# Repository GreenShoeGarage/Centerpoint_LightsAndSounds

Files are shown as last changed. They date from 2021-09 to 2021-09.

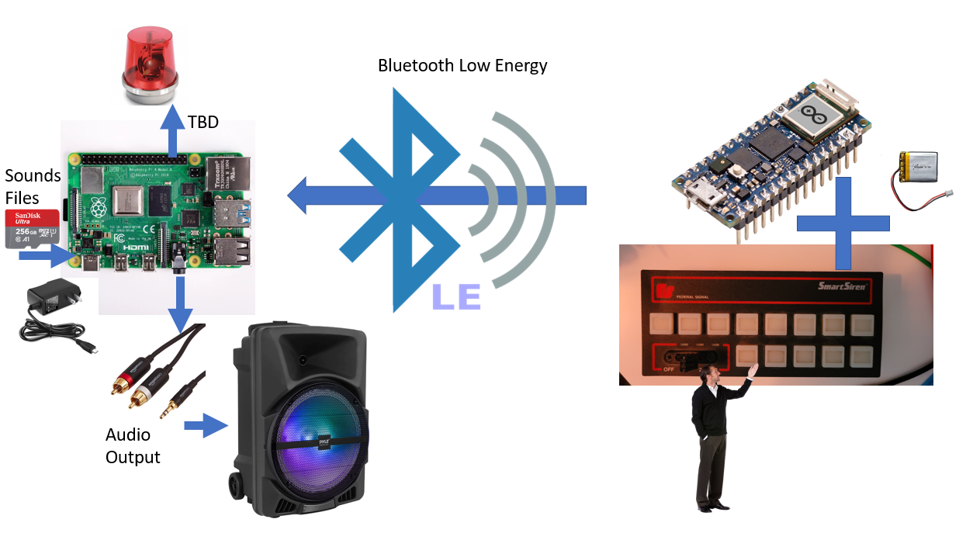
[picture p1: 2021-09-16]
Documentation/Photos/SystemArchitecture.png

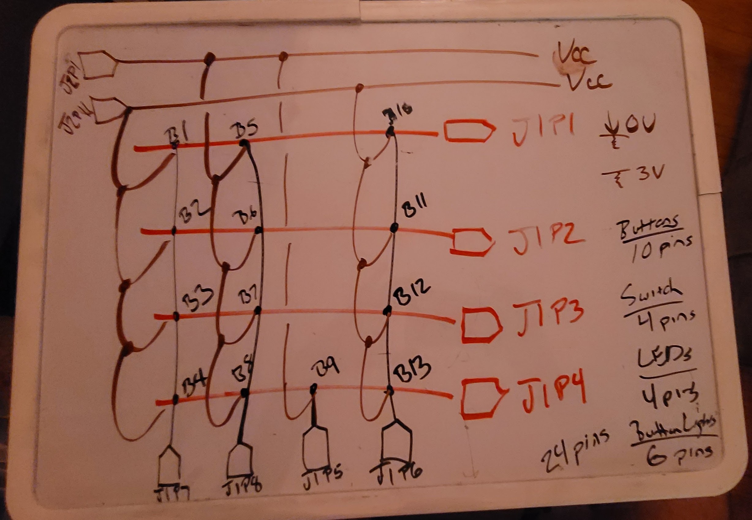
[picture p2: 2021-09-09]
Documentation/Photos/Keypad_MatrixCircuit.jpg

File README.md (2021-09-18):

# Centerpoint Lights and Sounds

| RP2040 Pin | Keypad PCB Header Row (J) | Keypad PCB Header Pin (P) | Pin Function |
|---|---|---|---|
| D2 | J1 | 5 | Keypad Column for Button 9 |
| D3 | J1 | 6 | Keypad Column for Buttons 10, 11, 12, 13 |
| D4 | J1 | 7 | Keypad Column for Buttons 1,2,3,4 |
| D5 | J1 | 8 | Keypad Column for Buttons 5, 6, 7, 8 |
| D6 | J2 | 1 | Keypad Row for Buttons 5, 6, 7, 8, 9 |
| D7 | J2 | 3 |  Button 1 LED GND AND GREEN LED GROUND |
| D8 | J2 | 5 |  Button 2 LED GND AND YELLOW LED GROUND |
| D9 | J2 | 7 |  GND for RED LED AND MAYBE  Button 3 LED GND**** |
| D10 | J2 | 11 | Keypad Row for Buttons 1,2,3,4,10,11,12,13 |
| D11 | SW | BLACK | VCC for Switch |
| D12 | J2 | 4 | Buttons 8 and 13 LED GND |
| D12 | J2 | 6 | Buttons 5 and 10 LED GND |
| D12 | J2 | 8 | Buttons 6 and 11 LED GND |
| D12 | J2 | 9 | Buttons 4 and 9 LED GND |
| D12 | J2 | 10 | Buttons 7 and 12 LED GND |
| D13 | SW | RED | Switch Position 2 |
| VCC | J2 | 2 | Top Row of Rubber Buttons (1-8) LED Vcc |
| VCC | J2 | 13 | Bottom Row of Rubber Buttons (9-13) LED Vcc AND  GYR LEDs Vcc |
| A0 | J1 | 1 | Buttons 1 and 5 and 10 |
| A1 | J1 | 2 | Buttons 2 and 6 and 11 |
| A2 | J1 | 3 |  Buttons 3 and 7 and 12 |
| A3 | J1 | 4 |  Buttons 4 and 8 and 9 and 13 |
| A4 | unassigned | unassigned | Reserved for I2C |
| A5 | unassigned | unassigned | Reserved for I2C |
| A6 | SW | GREEN | Switch Position 1 |
| A7 | SW | WHITE | Switch Position 3 |

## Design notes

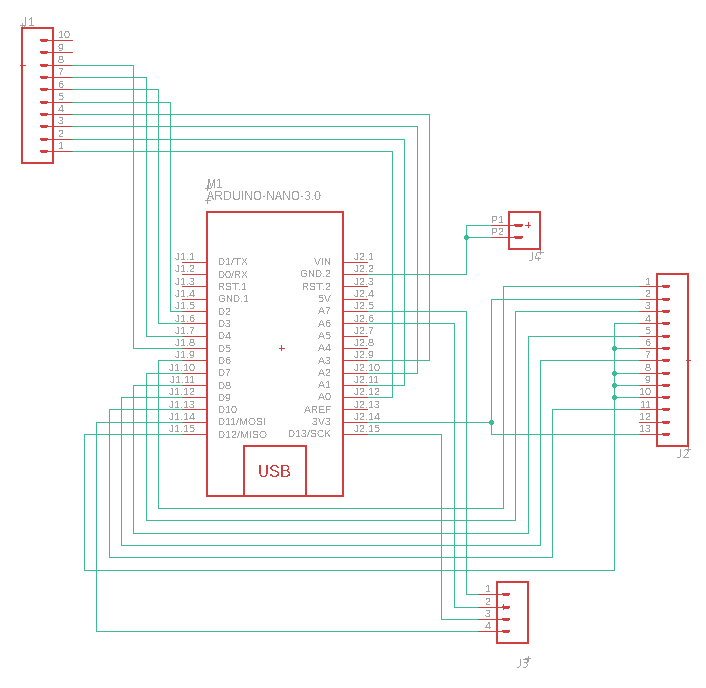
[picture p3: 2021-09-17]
Documentation/Photos/AdapterPCB_Schematic.png

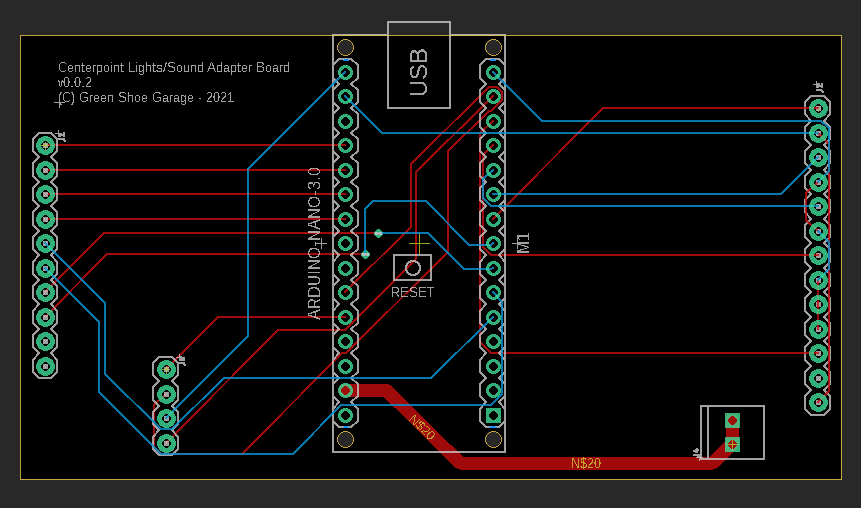
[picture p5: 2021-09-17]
Documentation/Photos/AdapterPCB_BoardLayout.png

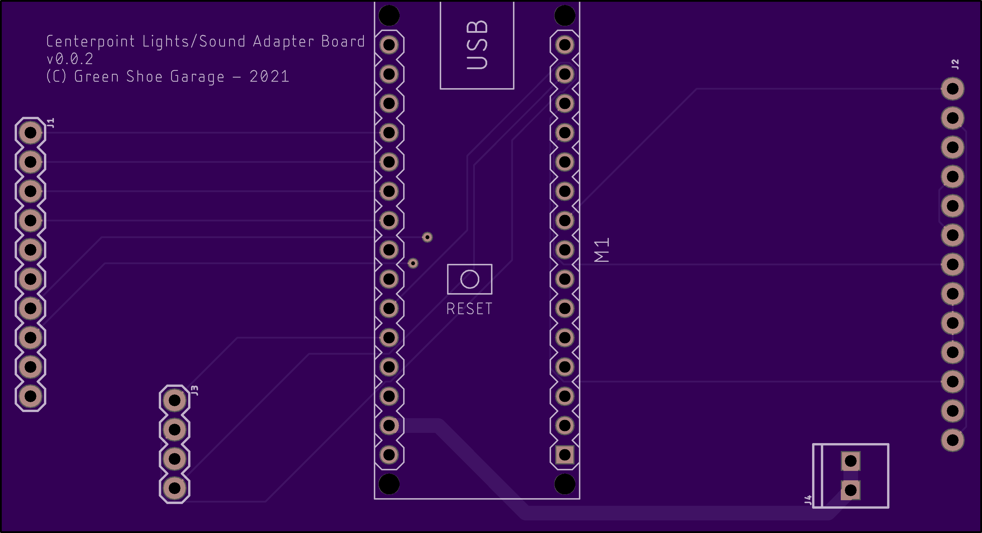
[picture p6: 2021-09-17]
Documentation/Photos/AdapterPCB_Top.png

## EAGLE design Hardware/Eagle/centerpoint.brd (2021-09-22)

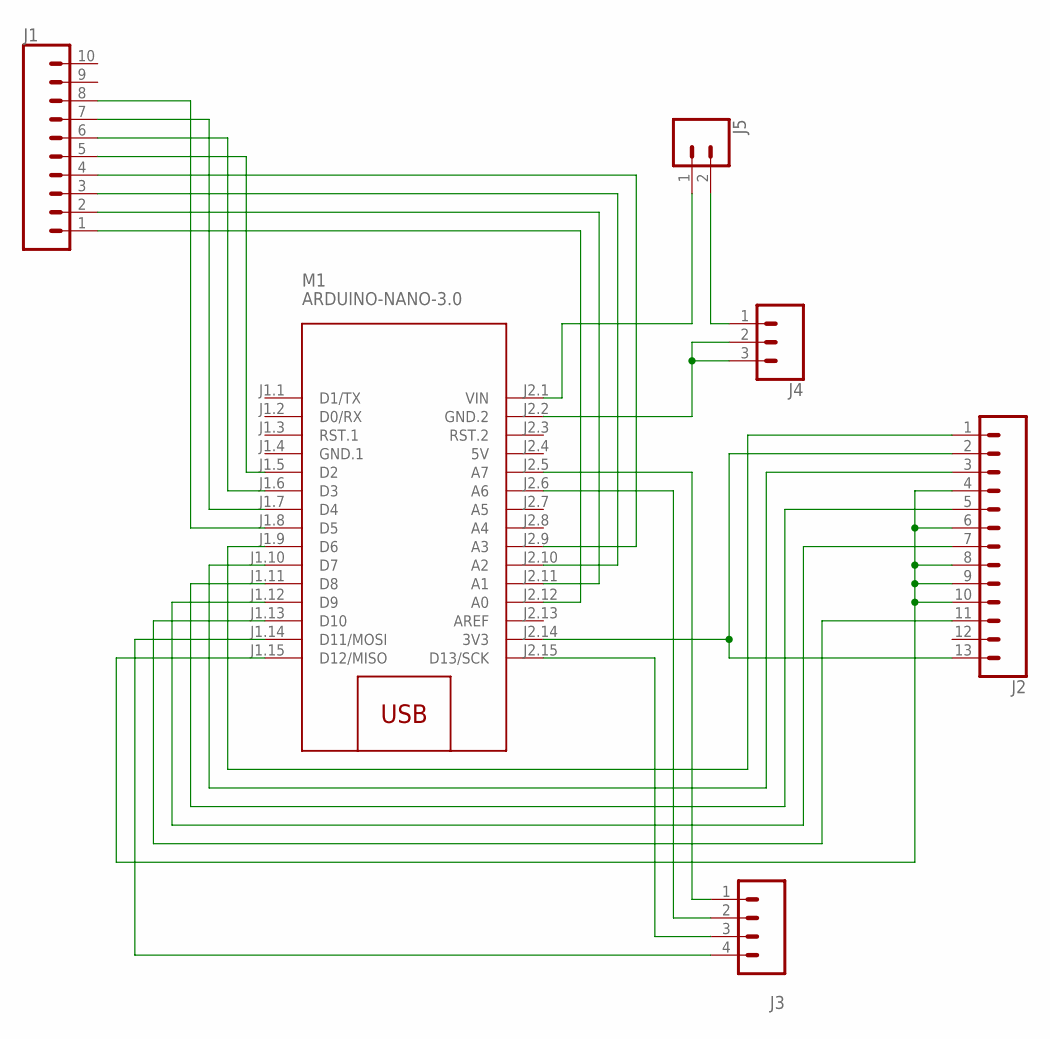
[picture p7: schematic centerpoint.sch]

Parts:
J1: CONN_10"; 1X10
J2: CONN_13; 1X13
J3: CONN_04PTH; 1X04
J4: CONN_03-SCREW-5MM; SCREWTERMINAL-5MM-3
J5: CONN_023.5MM; SCREWTERMINAL-3.5MM-2
M1: ARDUINO-NANO-3.0

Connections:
5V: M1.J2.4 (5V)
GND.1: M1.J1.4 (GND.1)
unnamed: J1.5, M1.J1.5 (D2)
unnamed: J1.6, M1.J1.6 (D3)
unnamed: J1.7, M1.J1.7 (D4)
unnamed: J1.8, M1.J1.8 (D5)
unnamed: J2.1, M1.J1.9 (D6)
unnamed: J2.3, M1.J1.10 (D7)
unnamed: J2.5, M1.J1.11 (D8)
unnamed: J2.7, M1.J1.12 (D9)
unnamed: J2.11, M1.J1.13 (D10)
unnamed: J3.4, M1.J1.14 (D11/MOSI)
unnamed: J2.4, J2.6, J2.8, J2.9, J2.10, M1.J1.15 (D12/MISO)
unnamed: J2.2, J2.13, M1.J2.14 (3V3)
unnamed: J1.1, M1.J2.12 (A0)
unnamed: J1.2, M1.J2.11 (A1)
unnamed: J1.3, M1.J2.10 (A2)
unnamed: J1.4, M1.J2.9 (A3)
unnamed: J3.1, M1.J2.5 (A7)
unnamed: J3.2, M1.J2.6 (A6)
unnamed: J3.3, M1.J2.15 (D13/SCK)
unnamed: J4.2, J4.3, M1.J2.2 (GND.2)
unnamed: J5.1, M1.J2.1 (VIN)
unnamed: J4.1, J5.2

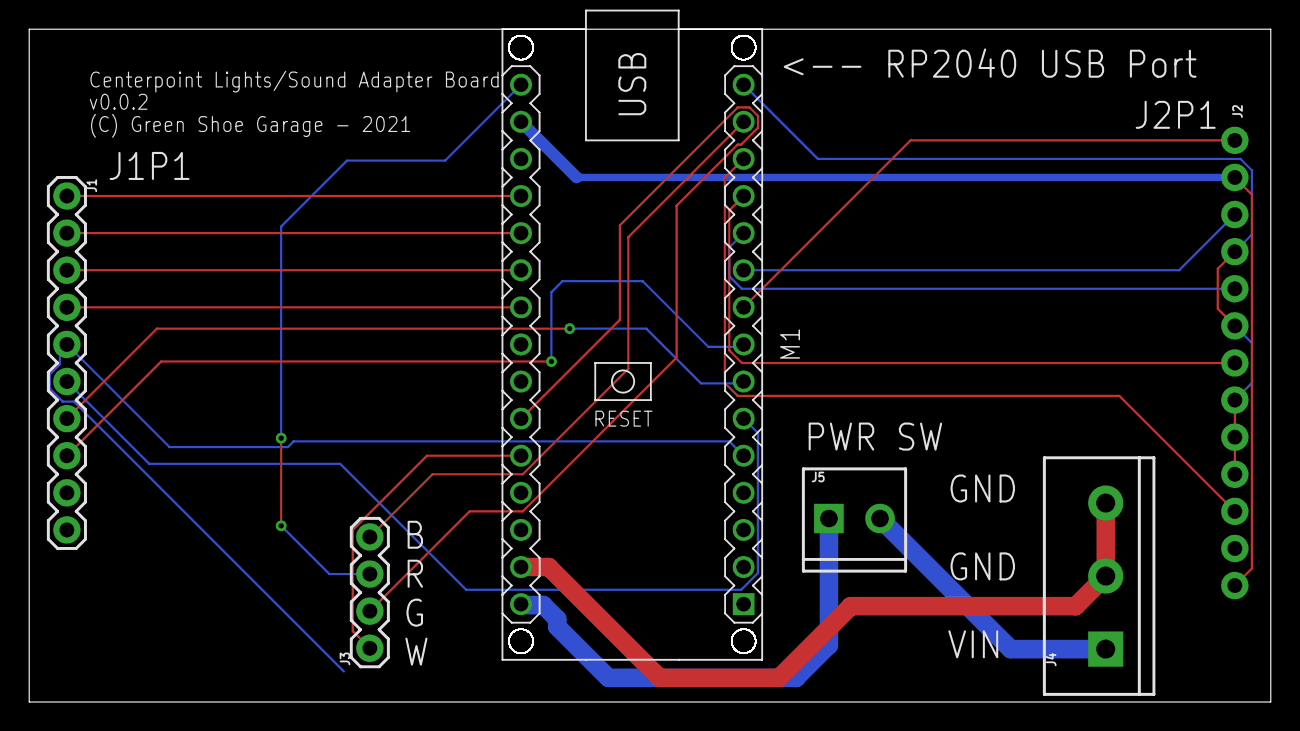
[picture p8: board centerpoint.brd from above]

Board: 2 copper layers, 85.0 x 46.1 mm, 6 parts (1 on the bottom side), 22 nets.

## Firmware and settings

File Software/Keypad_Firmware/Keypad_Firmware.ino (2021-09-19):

//COM4
#include <ArduinoBLE.h>
#include "WiFiNINA.h"



#define SW_BLACK_D11 11    // Switch Black Wire (COMMON)
#define SW_GREEN_A6 A6     // Switch Green Wire, Position 1
#define SW_RED_D13 13      // Switch Red Wire, Position 2
#define SW_WHITE_A7 A7     // Switch White Wire, Position 3

#define J1_P1_A0 A0       // Output for Buttons 1, 5, 10
#define J1_P2_A1 A1       // Output for Buttons 2, 6, 11
#define J1_P3_A2 A2       // Output for Buttons 3, 7, 12
#define J1_P4_A3 A3       // Output for Buttons 4, 8, 9, 13
#define J1_P5_D2 2         // Keypad Column for Button 9
#define J1_P6_D3 3         // Keypad Column for Buttons 10, 11, 12, 13
#define J1_P7_D4 4         // Keypad Column for Buttons 1, 2, 3, 4
#define J1_P8_D5 5         // Keypad Column for Buttons 5, 6, 7, 8
#define J2_P1_D6 6         // Keypad Row for Buttons 5, 6, 7, 8, 9
#define J2_P11_D10 10      // Keypad Row for Buttons 1,2,3,4,10,11,12,13

#define J2_P3_D7 7         // Button 1 LED GND   and    GREEN LED GND
#define J2_P5_D8 8         // Button 2 LED GND   and    YELLOW LED GND
#define J2_P7_D9 9         // Button 3 LED GND   and    RED LED GND
#define J2_LEDGND_D12 12   // All Other Buttons LED GND

byte inputArray[16] = {0};  //Switch Position 1,2,3 = G-A6,R-D13,W-A7

BLEService LEDService("19B10000-E8F2-537E-4F6C-D104768A1214"); // BLE LED Service
// BLE LED Switch Characteristic - custom 128-bit UUID, read and writable by central
BLECharacteristic LEDCharacteristic("19B10001-E8F2-537E-4F6C-D104768A1214", BLERead | BLENotify | BLEWrite, 16);

void setup() {

  Serial.begin(9600);

  // begin initialization
  if (!BLE.begin()) {
    Serial.println("starting BLE failed!");
  }
  // set advertised local name and service UUID:
  BLE.setLocalName("Button LED Device");
  BLE.setAdvertisedService(LEDService);
  // add the characteristic to the service
  LEDService.addCharacteristic(LEDCharacteristic);
  // add service
  BLE.addService(LEDService);
  // start advertising
  BLE.advertise();
  Serial.println("BLE LED Peripheral, waiting for connections....");

  pinMode(J1_P5_D2, OUTPUT);
  pinMode(J1_P6_D3, OUTPUT);
  pinMode(J1_P7_D4, OUTPUT);
  pinMode(J1_P8_D5, OUTPUT);
  pinMode(J2_P1_D6, OUTPUT);
  pinMode(J2_P11_D10, OUTPUT);
  digitalWrite(J1_P5_D2, LOW);
  digitalWrite(J1_P6_D3, LOW);
  digitalWrite(J1_P7_D4, LOW);
  digitalWrite(J1_P8_D5, LOW);
  digitalWrite(J2_P1_D6, LOW);
  digitalWrite(J2_P11_D10, LOW);

  pinMode(J2_P3_D7, OUTPUT);
  pinMode(J1_P5_D2, OUTPUT);
  pinMode(J1_P5_D2, OUTPUT);
  digitalWrite(J2_P3_D7, HIGH);
  digitalWrite(J1_P5_D2, HIGH);
  digitalWrite(J1_P5_D2, HIGH);

  pinMode(SW_BLACK_D11, OUTPUT);
  pinMode(J2_LEDGND_D12, OUTPUT);
  digitalWrite(SW_BLACK_D11, HIGH);
  digitalWrite(J2_LEDGND_D12, HIGH);

}






void loop() {
  // listen for BLE peripherals to connect:
  BLEDevice central = BLE.central();
  // if a central is connected to peripheral:
  if (central) {
    Serial.print("Connected to central: ");
    // print the central's MAC address:
    Serial.println(central.address());
    // while the central is still connected to peripheral:
    while (central.connected()) {
      readInputs();
      displayInputs();
      LEDCharacteristic.writeValue(inputArray, sizeof(inputArray));
    }
    // when the central disconnects, print it out:
    Serial.print(F("Disconnected from central: "));
    Serial.println(central.address());
  }
}



void readInputs() {

  digitalWrite(J2_P11_D10, HIGH);             // Keypad Row for Buttons 1,2,3,4,10,11,12,13
  digitalWrite(J2_P1_D6, LOW);                // Keypad Row for Buttons 5, 6, 7, 8, 9
  digitalWrite(J1_P7_D4, HIGH);               //Col for buttons 1-4
  digitalWrite(J1_P8_D5, LOW);                //Col for buttons 5-8
  digitalWrite(J1_P5_D2, LOW);                //Col for Button 9
  digitalWrite(J1_P6_D3, LOW);                //Col for Buttons 10-13
  delay(100);
  inputArray[0] = analogRead(J1_P1_A0);     //Output for Buttons 1, 5, 10
  inputArray[1] = analogRead(J1_P2_A1);     //Output for Buttons 2, 6, 11
  inputArray[2] = analogRead(J1_P3_A2);     //Output for Buttons 3, 7, 12
  inputArray[3] = analogRead(J1_P4_A3);     //Output for Buttons 4, 8, 9, 13


  digitalWrite(J2_P11_D10, LOW);              // Keypad Row for Buttons 1,2,3,4,10,11,12,13
  digitalWrite(J2_P1_D6, HIGH);               // Keypad Row for Buttons 5, 6, 7, 8, 9
  digitalWrite(J1_P7_D4, LOW);                //Col for buttons 1-4
  digitalWrite(J1_P8_D5, HIGH);               //Col for buttons 5-8
  digitalWrite(J1_P5_D2, LOW);                //Col for Button 9
  digitalWrite(J1_P6_D3, LOW);                //Col for Buttons 10-13
  delay(100);
  inputArray[4] = analogRead(J1_P1_A0);     //Output for Buttons 1, 5, 10
  inputArray[5] = analogRead(J1_P2_A1);     //Output for Buttons 2, 6, 11
  inputArray[6] = analogRead(J1_P3_A2);     //Output for Buttons 3, 7, 12
  inputArray[7] = analogRead(J1_P4_A3);     //Output for Buttons 4, 8, 9, 13


  digitalWrite(J2_P11_D10, LOW);              // Keypad Row for Buttons 1,2,3,4,10,11,12,13
  digitalWrite(J2_P1_D6, HIGH);               // Keypad Row for Buttons 5, 6, 7, 8, 9
  digitalWrite(J1_P7_D4, LOW);                //Col for buttons 1-4
  digitalWrite(J1_P8_D5, LOW);                //Col for buttons 5-8
  digitalWrite(J1_P5_D2, HIGH);               //Col for Button 9
  digitalWrite(J1_P6_D3, LOW);                //Col for Buttons 10-13
  delay(100);
  inputArray[8] = analogRead(J1_P4_A3);     //Output for Buttons 4, 8, 9, 13


  digitalWrite(J2_P11_D10, HIGH);             // Keypad Row for Buttons 1,2,3,4,10,11,12,13
  digitalWrite(J2_P1_D6, LOW);                // Keypad Row for Buttons 5, 6, 7, 8, 9
  digitalWrite(J1_P7_D4, LOW);                //Col for buttons 1-4
  digitalWrite(J1_P8_D5, LOW);                //Col for buttons 5-8
  digitalWrite(J1_P5_D2, LOW);                //Col for Button 9
  digitalWrite(J1_P6_D3, HIGH);               //Col for Buttons 10-13
  delay(100);
  inputArray[9] = analogRead(J1_P1_A0);     //Output for Buttons 1, 5, 10
  inputArray[10] = analogRead(J1_P2_A1);    //Output for Buttons 2, 6, 11
  inputArray[11] = analogRead(J1_P3_A2);    //Output for Buttons 3, 7, 12
  inputArray[12] = analogRead(J1_P4_A3);    //Output for Buttons 4, 8, 9, 13


  inputArray[13] = 0; //analogRead(A6);
  inputArray[14] = digitalRead(13);
  inputArray[15] = 0; //analogRead(A7);

}



void displayInputs() {

  Serial.print("Button status: ");
  for (int x = 0; x < 13; x++) {
    Serial.print(inputArray[x]); Serial.print(",");
  }
  Serial.println();


  Serial.print("Switch status: ");
  for (int x = 13; x < 16; x++) {
    Serial.print(inputArray[x]); Serial.print(",");
  }
  Serial.println();
}

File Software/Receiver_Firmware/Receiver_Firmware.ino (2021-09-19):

//COM3 - BLE Central
#include <ArduinoBLE.h>


void setup() {
  Serial.begin(9600);
  //while (!Serial);
  // initialize the BLE hardware
  BLE.begin();
  Serial.println("BLE Central - LED control");
  Serial.print("My address: "); Serial.println(BLE.address());
  // start scanning for LED BLE peripherals
  BLE.scanForUuid("19b10000-e8f2-537e-4f6c-d104768a1214");
}
void loop() {
  // check if a peripheral has been discovered
  BLEDevice peripheral = BLE.available();
  if (peripheral) {
    // discovered a peripheral, print out address, local name, and advertised service
    Serial.print("Found ");
    Serial.print(peripheral.address());
    Serial.print(" '");
    Serial.print(peripheral.localName());
    Serial.print("' ");
    Serial.print(peripheral.advertisedServiceUuid());
    Serial.println();
    if (peripheral.localName().indexOf("LED") < 0) {
      Serial.println("No 'LED' in name");
      return;  // If the name doeshn't have "LED" in it then ignore it
    }
    // stop scanning
    BLE.stopScan();

    controlLed(peripheral);
    // peripheral disconnected, start scanning again
    BLE.scanForUuid("19b10000-e8f2-537e-4f6c-d104768a1214");
  }
}
void controlLed(BLEDevice peripheral) {
  // connect to the peripheral
  Serial.println("Connecting ...");
  if (peripheral.connect()) {
    Serial.println("Connected");
  } else {
    Serial.println("Failed to connect!");
    return;
  }
  // discover peripheral attributes
  Serial.println("Discovering attributes ...");
  if (peripheral.discoverAttributes()) {
    Serial.println("Attributes discovered");
  } else {
    Serial.println("Attribute discovery failed!");
    peripheral.disconnect();
    return;
  }
  // retrieve the LED characteristic
  BLECharacteristic LEDCharacteristic = peripheral.characteristic("19b10001-e8f2-537e-4f6c-d104768a1214");
  if (!LEDCharacteristic) {
    Serial.println("Peripheral does not have LED characteristic!");
    peripheral.disconnect();
    return;
  }


  while (peripheral.connected()) {
    // while the peripheral is connected
    if (LEDCharacteristic.canRead()) {
      byte value[16] = {0};
      //value = LEDCharacteristic.read();
      LEDCharacteristic.readValue(value, 16);

      for (int x = 0; x < 16; x++) {
        Serial.print(value[x]); Serial.print(",");
        switch (x) {
          case 0:
            if ( value[x] > 250) {
              digitalWrite(13, HIGH);
            }
            break;
          case 1:
            if ( value[x] > 250) {
              digitalWrite(13, LOW);
            }
            break;
          case 13:
            if ( value[x] > 250) {
            }
            break;
          case 14:
            if ( value[x] == 1) {
            }
            break;
          case 15:
            if ( value[x] > 250) {
            }
            break;
          default:
            break;

        }
      }
    }
    Serial.println();
  }

  Serial.println("Peripheral disconnected");
}

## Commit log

2021-09-16 baseline functionality achieved for all buttons and switch positions
2021-09-16 init BRD and SCH commit for interface board
    [centerpoint.brd, centerpoint.sch]
2021-09-17 Added PCB docs
2021-09-17 Adjusted Switch pin assignments
2021-09-17 updated adapter board PCB layout
    [centerpoint.brd, centerpoint.sch]
2021-09-17 corrected placement of GND screw terminal and switch interface header
    [centerpoint.brd]
2021-09-17 revised images based on v0.0.2 of PCB
2021-09-18 added to silkscreen, change from 2.54 to 5mm screw terminal
    [centerpoint.brd, centerpoint.sch]
2021-09-19 print the MAC address of central device
2021-09-19 reworked board layout
    [centerpoint.brd]
2021-09-22 added power switch and screw terminal for battery (VIN)
    [centerpoint.brd, centerpoint.sch]
2021-09-23 detect individual button presses in RPi Python script

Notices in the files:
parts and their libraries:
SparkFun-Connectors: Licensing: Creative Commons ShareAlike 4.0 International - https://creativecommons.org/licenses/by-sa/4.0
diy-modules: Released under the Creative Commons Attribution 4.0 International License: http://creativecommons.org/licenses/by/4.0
